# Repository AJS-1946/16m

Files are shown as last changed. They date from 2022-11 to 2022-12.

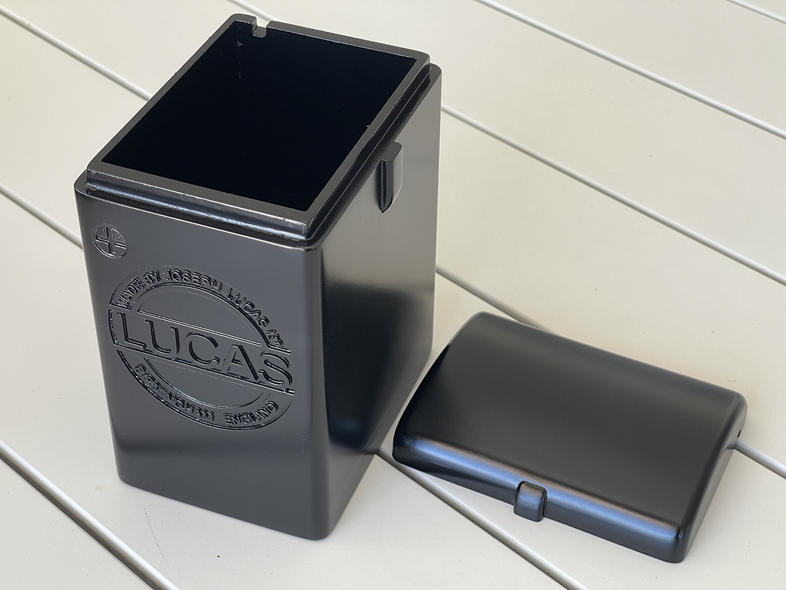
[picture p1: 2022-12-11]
Battery Box/Finished Box1.JPG

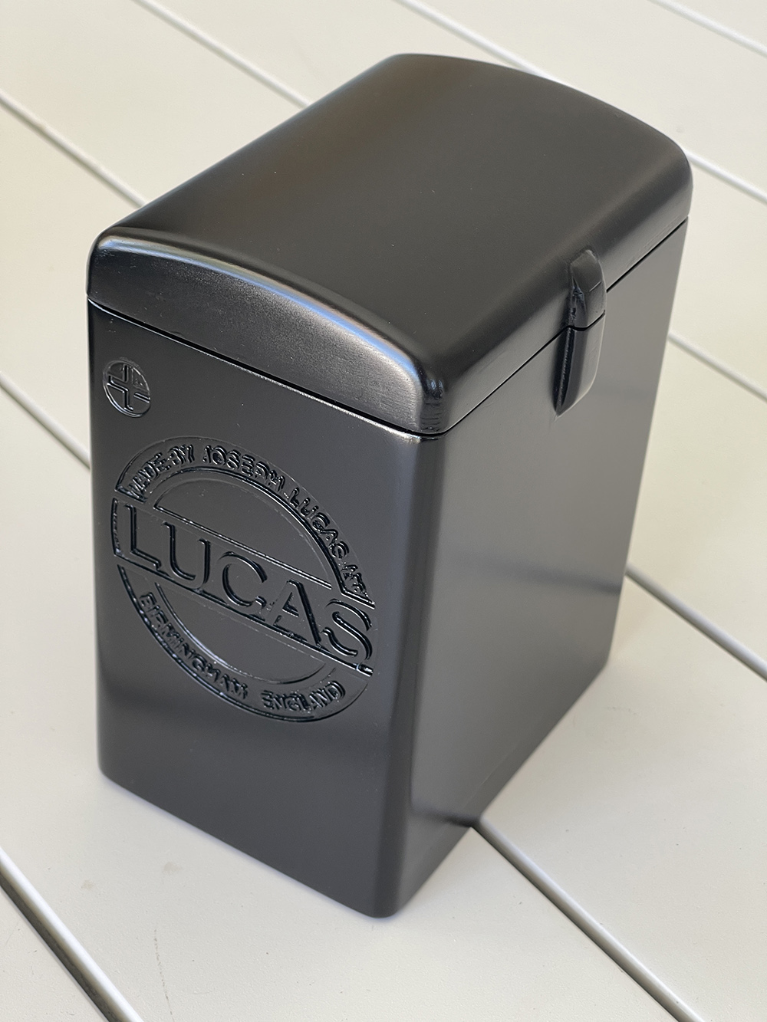
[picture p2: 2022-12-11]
Battery Box/Finished Box2.JPG

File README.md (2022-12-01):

# AJS 16M components

This repository constains manufacturing information for parts I have created during the restoration of my 1946 AJS 16M 350cc motorcycle.

These components are also shared by AJS 16M and 18M models for several years after 1946, as well as by the Matchless G3L from 1941 onwards, and the Matchless G80.

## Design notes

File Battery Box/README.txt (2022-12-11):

3D printed Lucas PUW7E Battery Box

This model consists of four components, the main battery box, a separately printed box side insert containing the LUCAS logo, the top of the lid and the rim of the lid. Once printed, the two pieces of the lid need to be glued together using super glue. The box side containing the logo also need to be glued in place on the side of the main box.

These parts are contained in four files:

BatteryBoxBody.3mf
BatteryBoxInset.3mf
BatteryBoxLidTop.3mf
BatteryBoxRim.3mf

At the present time the logo is an approximation of the post-war Lucas logo used on the original batteries. However if I am able to achieve a sufficiently accurate reproduction of the WD battery logo I will release this as a separate inset part in the future.

Printing
Recommended printing material is PETG, although PLA with a high fill percentage should also give adequate strength and dimensional stability. The rim of the lid should be printed with an infill percentage of around 60% in order to improve the dimensional stability of the lid, other parts can be printed with an infill percentage of 15%.

After testing initial prototypes, it is recommended that the top portion of the lid also be printed with a higher infill percentage to prevent it bowing in hot sunlight, as the top of the lid is a horizontal surface so gets the most sun, and the battery box is typically black for civilian bikes. For hot climates this could be as high as 60%, for cooler climates 30% should be adequate. Alternatively, interior vertical ribbing running along the long axis of the lid may be added.

To date, these parts have been printed using a Prusa Mk3S printer with good results, but have not been tested with other printers. If you have access to a Prusa Mk3S, Gcode files have been included for this printer

Finishing
To finish, sand with 80 or 120 grit paper to help paint to adhere to the surface, or use a furniture scraper to smooth the ridges left from 3D printing. After initial sanding, apply one or more coats of high-build undercoat, then wet-sand back using 100 - 120 grit wet-or-dry paper. Wet-sanding allows the fairly soft printed filament to sand cleanly without softening due to heat, which can result in furring of the surface. Repeat until you get a smooth surface, then spray a couple of coats of satin or matt finish top coat. 

Usage
The battery box is designed to house two Lucas 6 volt, LSLA4-6 batteries (or similar) side by side, wired in parallel for 6v or in series for 12v.

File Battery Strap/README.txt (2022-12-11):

Laser cut strap to fit AJS 16M and 18M, and Matchless G3L and G80 from the 1940s.

This strap is designed to fit a Lucas PUW7E Battery or similar. If you don't have a battery that fits this shape, please see the 3D printed battery box project in this repository

The BatteryStrapOutline_mm.dxf file in this repository is a 2D path for laser cutting a battery strap, which can then be bent to suit the shape of the battery. Note that units used in the file are millimetres. No kerf has been deducted from this path.

Strap should be cut from 1.2mm mild steel or similar.

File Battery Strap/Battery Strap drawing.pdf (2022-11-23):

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

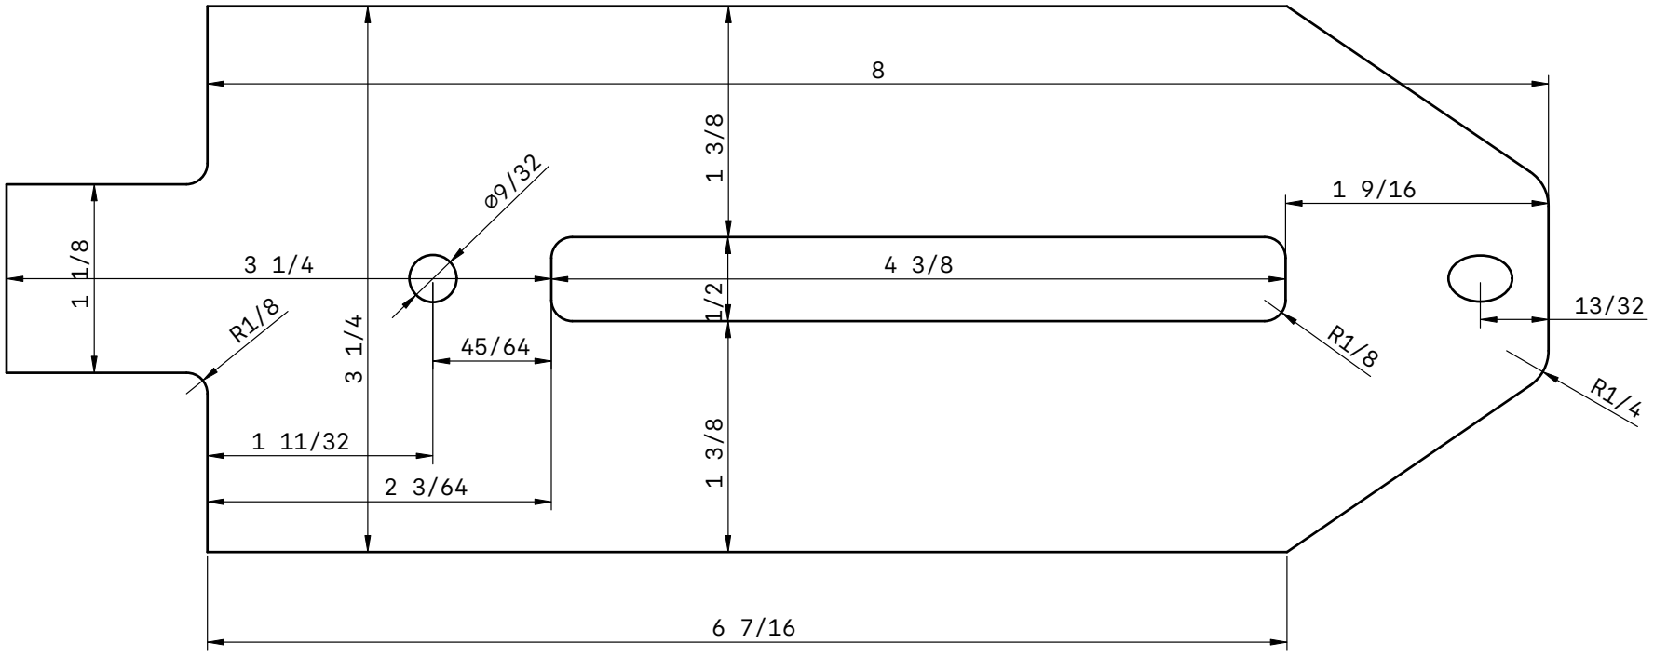
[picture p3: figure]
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

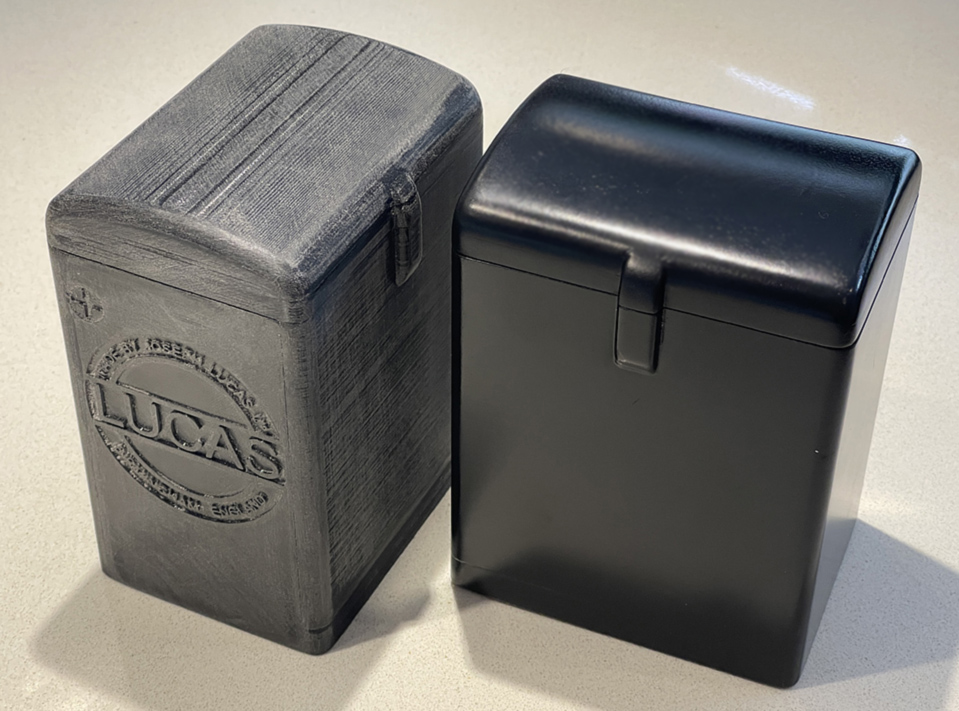
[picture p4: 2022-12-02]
Battery Box/before and after painting.JPG

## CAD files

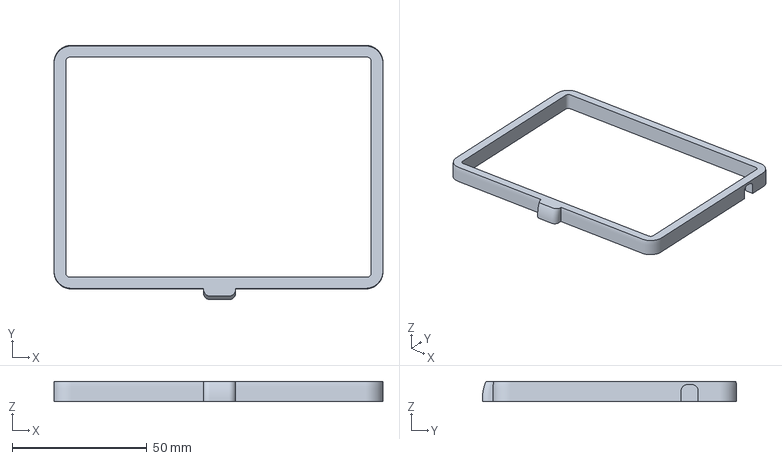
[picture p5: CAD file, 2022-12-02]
Battery Box/BatteryBoxRim.3mf
122.2 x 94.5 x 7.54 mm

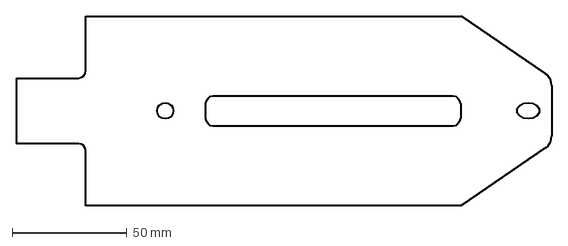
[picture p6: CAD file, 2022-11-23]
Battery Strap/BatteryStrapOutline_mm.dxf
233.6 x 82.7 mm

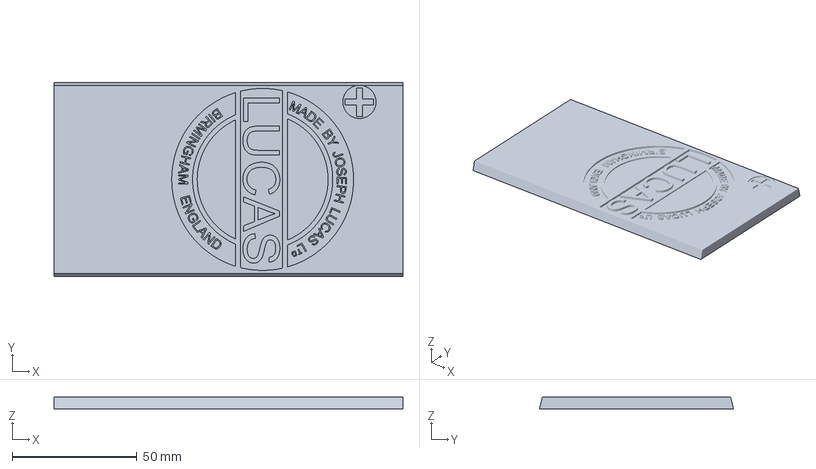
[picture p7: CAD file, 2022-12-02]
Battery Box/BatteryBoxInset.3mf
139.7 x 77.8 x 4.76 mm

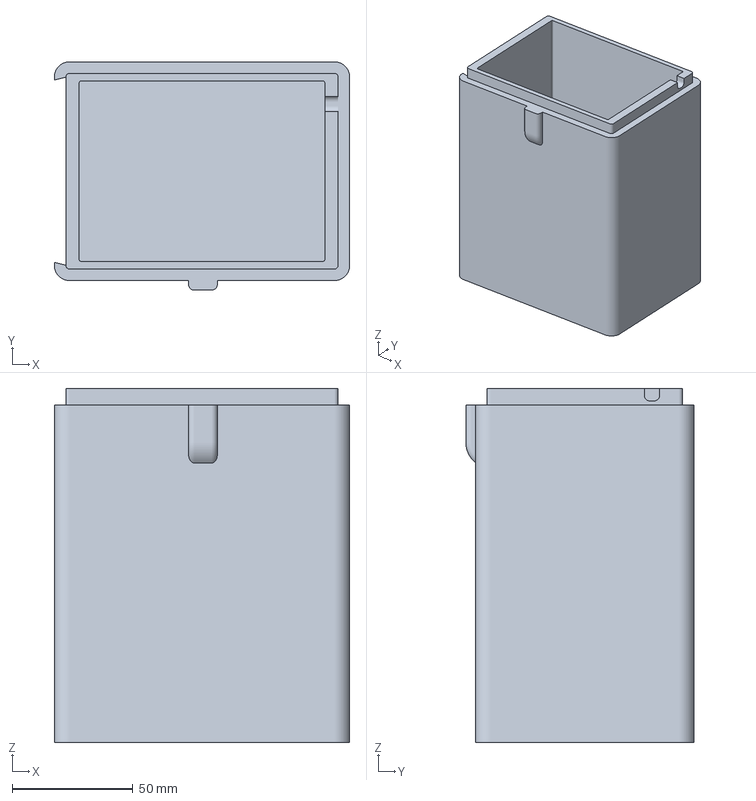
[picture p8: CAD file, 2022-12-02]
Battery Box/BatteryBoxBody.3mf
122.2 x 94.5 x 146.4 mm

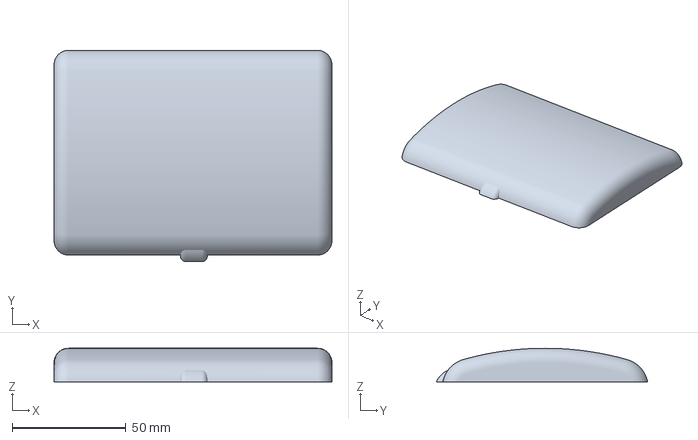
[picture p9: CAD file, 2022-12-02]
Battery Box/BatteryBoxLidTop.3mf
122.2 x 92.9 x 14.7 mm

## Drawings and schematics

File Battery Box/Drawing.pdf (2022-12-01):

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

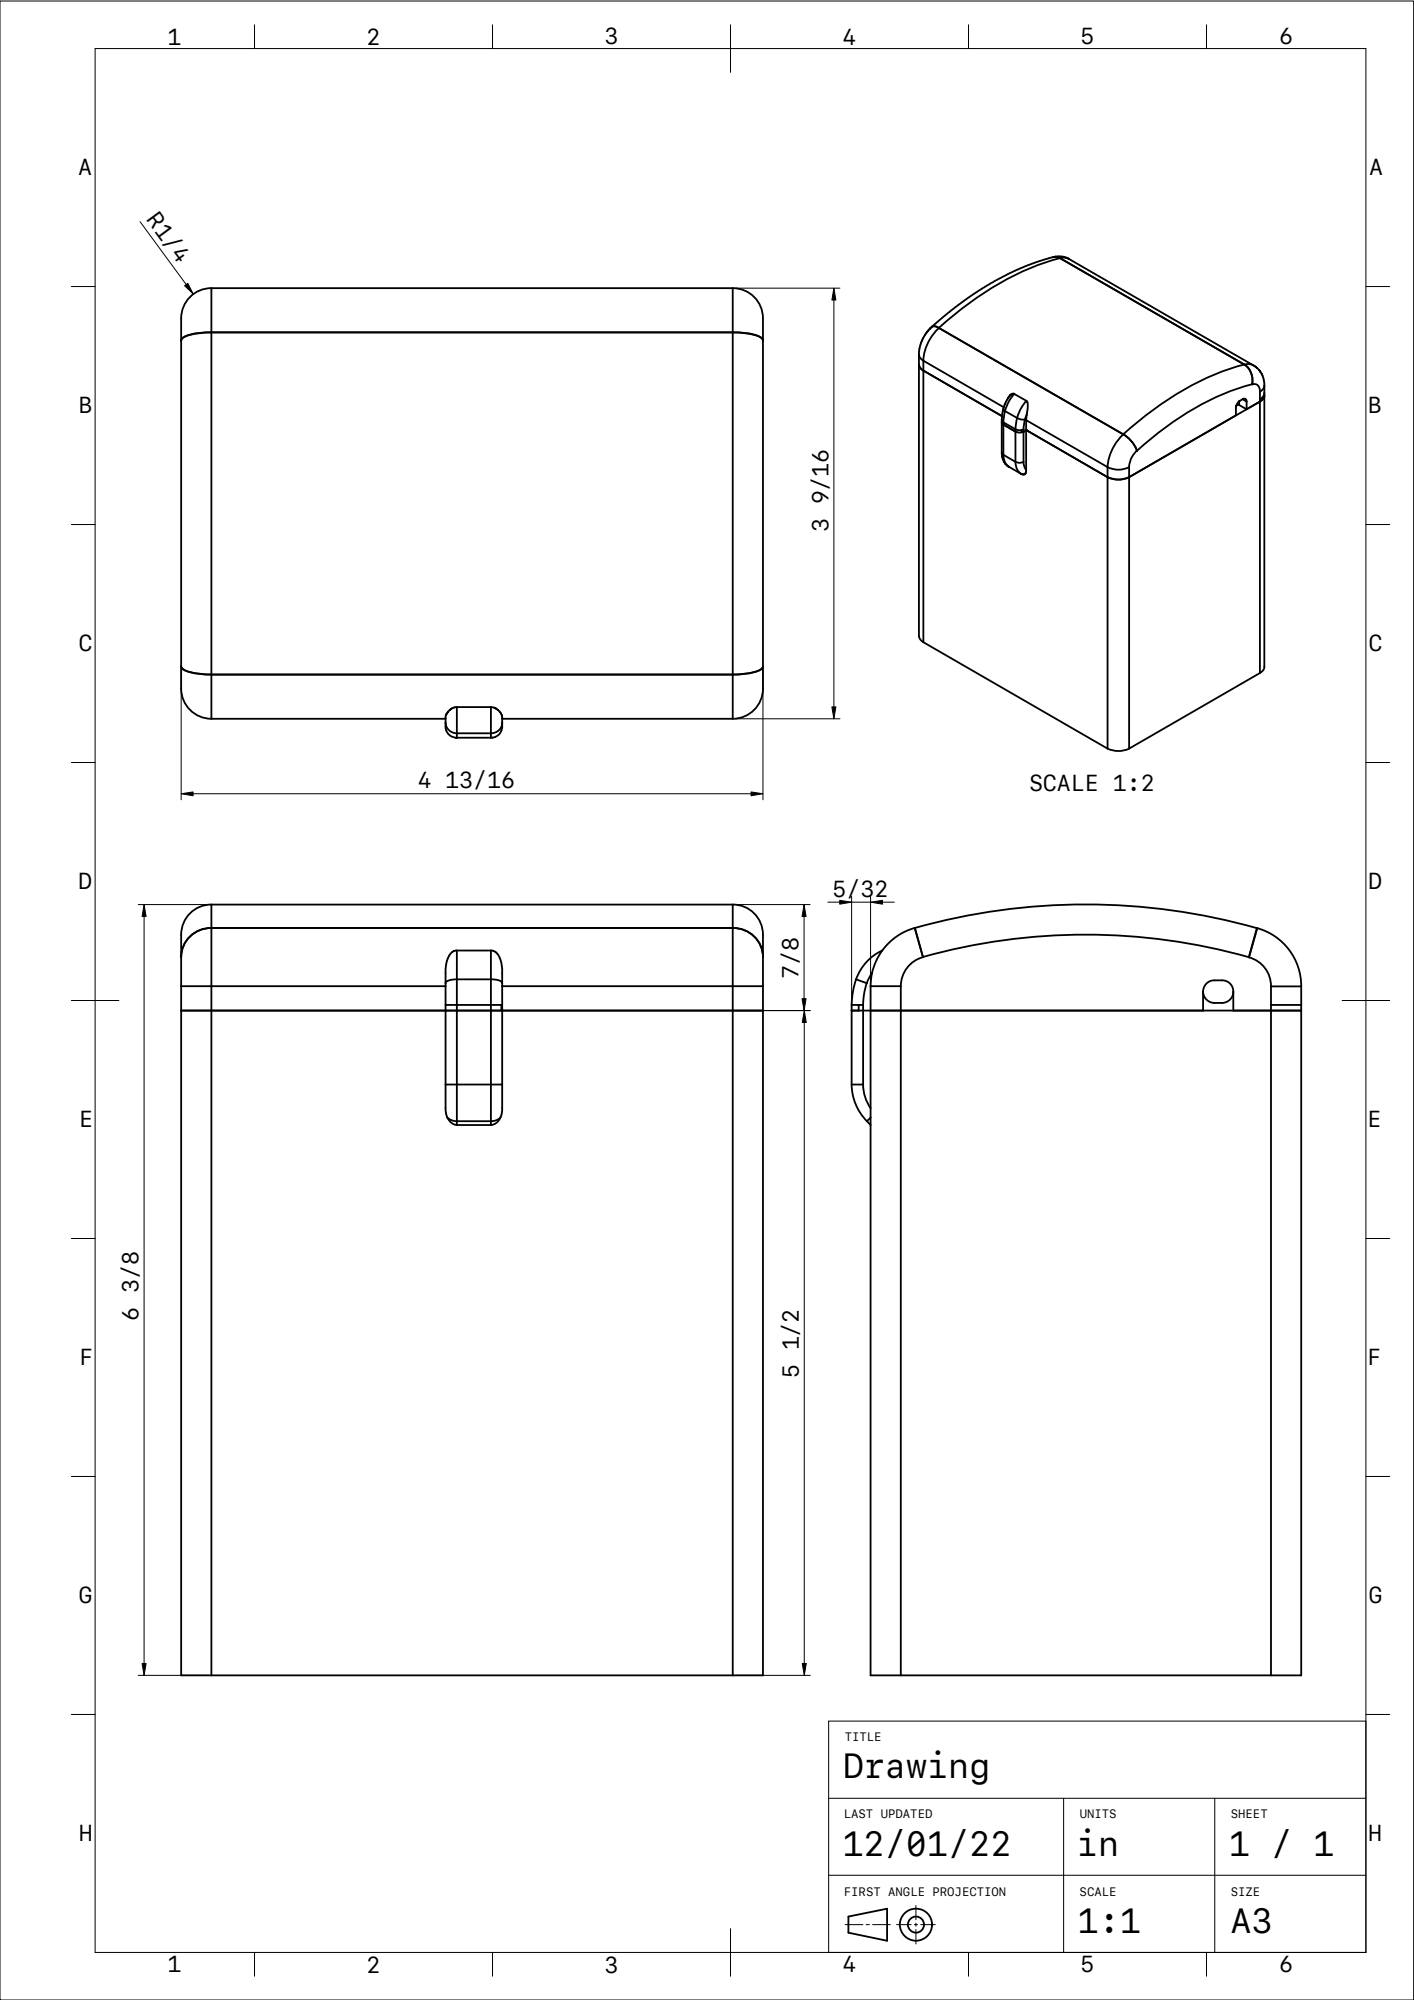
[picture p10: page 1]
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

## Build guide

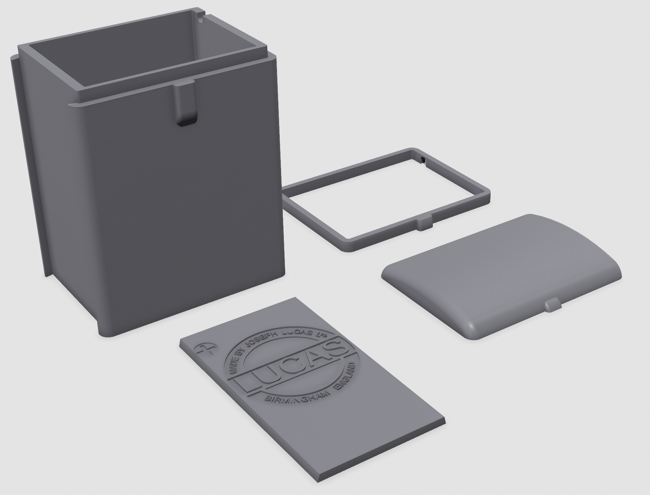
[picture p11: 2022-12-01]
Battery Box/printed components.png

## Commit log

2022-11-23 initial readme commit
    initial commit battery box readme file
2022-11-23 Initial commits
    [BatteryStrapOutline_mm.dxf]
2022-12-02 First 3D files
    [BatteryBoxBody.3mf, BatteryBoxInset.3mf, BatteryBoxLidTop.3mf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]
2022-12-11 Update BatteryBoxLidTopSlicer_0.15mm_PETG_MK3S_7h52m.gcode
    Increase infill percentage from 30% to 50% to reduce warping in high temperatures
2022-12-11 Add photos of painted battery box with logo
